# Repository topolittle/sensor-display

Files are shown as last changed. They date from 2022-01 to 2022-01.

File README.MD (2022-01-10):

# Sensor display monitor
This is a complete project to display temperature, fan speed and power consumption to a small 2x20 LCD display. The head unit fits a 5.25 standard PC drive bay.

## Features
Head unit:
- Arduino based
- 6 modes of operation
- Enclosure printable without supports

SystemD service (PC):
- Fully customizable using a configuration file
- Installation script included
- Written in Python
- Linux Support

## What's included
- Bill of material
- 3D Models (Step, Solidwork and STL)
- Electrical schematic
- Source code for the head unit (Arduino based)
- Source code for the service that monitor and send the data to the head unit
- VSCode devcontainer environment for the service and the head unit
- Some pictures of the final product

## Licenses
[Mechanical parts](MECHA/COPYING.TXT)  
[Head unit (Arduino)](SOFT/Arduino/COPYING.TXT)  
[SystemD Service (PC)](SOFT/PC/COPYING.TXT)  

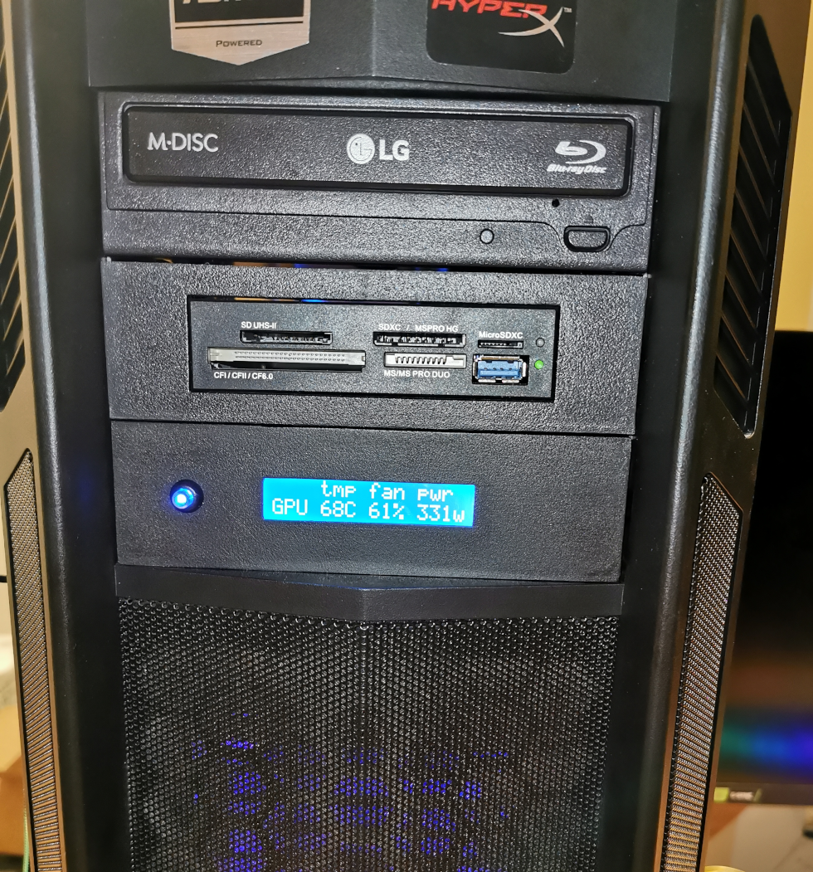
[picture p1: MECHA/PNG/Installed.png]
Picture of the head unit installed into a PC enclosure


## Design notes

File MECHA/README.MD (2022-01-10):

# Sensor display unit enclosure

This enclosure has been designed to fit into a 5.25" PC bay.

## Printer setting
Printed on a Flashforge Creator Pro FDM 3D printer.
- Material: ASA (Formfutura ApolloX)
- Position: Front panel face down on the bed
- Supports: No
- Finish: Some Acetone smooting for the front panel

## Credits
The assembly and the artwork uses some 3rd parties parts. Here is the list:  
**Pro micro Arduino PCB**  
Author: Andrew_Whitham  
URL: https://grabcad.com/library/arduino-pro-micro-1

**LCD Display**  
Author: Vin.X.Mod  
URL: https://grabcad.com/library/1602-lcd-display-1  

**M2 Screws**  
Author: Ioan Skurka  
URL: https://grabcad.com/library/all-m2-sh-standard-screws-m2-hex-nut-and-flat-washer-for-m2-screw-1

**5.25" drive bay**  
Author: Shashank Chintalagiri  
URL: https://grabcad.com/library/generic-5-25-bay-devices-1  
Note: This modes was used only for reference mesurements.

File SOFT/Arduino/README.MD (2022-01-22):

# SENSOR DISPLAY UNIT - EMBEDDED CODE
This is the code for the sensor display unit.
It target the Keystudio Ks0503 Pro Micro board but any Atmel ATMEGA 32U4 Arduino
board with an Leonardo bootloader should do the job. It's designed to fit in
a standard 5.25" PC drive bay.  
The device is powered by a single Molex 4 pin PC power connecter and it gets its data from a service running on the PC through an RS232 serial connection.

Please refers to the schematic diagram for the wiring of the board.
For the complete part list, refers to the bill of material document (BOM).

## Features
The unit has two modes of operation:
- Sensor display
- Configuration
In the sensor display mode, the display will display the current stored sensors values.
In the configuration mode, the display will cycle through all the available settings. Refers to the 'settings' section for more information.

## Settings
When pushing the button, the unit enters the configuration mode. Each subsequent button push will cycle to the next setting. Here is the list of all available configuration:
- SYSTEM: Display the system temperature and fan RPM
- CPU: Display the CPU temperature and fan RPM
- GPU: Display the GPU temperature, fan percentage and power consumption
- ALL (TEMP): Display the system, CPU and GPU temperature
- ALL (FAN): Display the system, CPU and GPU fan RPM or percentage
- AUTO: Cycle through SYSTEM, CPU and GPU every 3 seconds
- BUTTON LED OFF: Turn off the button blue LEDssss
- BUTTON LED HIGH: Turn on the button blue LED at high intensity
- BUTTON LED LOW: Turn on the button blue LED at low intensity

After 3 seconds of inactivity, the unit will revert to sensor display mode, the new configuration is saved to the persistent memory (EEProm) and it take effect immediately.

## Dependencies
The code requires the following libraries to be installed:  
**LiquidCrystal I2C**  
Version: 1.1.2  
Author: Frank de Brabander  
URL: https://github.com/marcoschwartz/LiquidCrystal_I2C

**Wire (Build-in library)**  
Version: 1.0.0  
Author: Nicholas Zambetti  
URL: https://www.arduino.cc/en/Reference/Wire

**EEPROM (Build-in library)**  
Version: 2.0.0  
Authors: David A. Mellis. and Christopher Andrews  
URL: https://www.arduino.cc/en/Reference/EEPROM

Note: If your are using the included VSCode devcontainer, libraries are already included and installed.

# Serial commands
Each serial command has the forms of `CCV..V;` where:
- 'CC' is a two chars command code
- 'V' is one or more numeric char that form the value associated with the command
- ';' is a marker char and signals the end of a command  
 Multiple command can be received on the same line, for example the
 command `ST34;CT55;GT67;CF1152;` will sets the system temperature
 to 34 celcius, the CPU temperature to 55 celcius and the CPU fan speed to 1152 RPM.  
 Refer to the source code to the complete list of accepted commands.
 
# Using with Visual Studio Code
## Using the devcontainer
The devcontainer is a self-contained environment that allows to compiles and upload
Arduino source code without having to install anything on your computer. You just need Docker.
[More Information about VSCode devcontainer here.](https://code.visualstudio.com/docs/remote/containers)
1. Open this folder (where this README.MD is located)
2. Hit Shift-CTRL-P  to open the command palette
3. Type and select: Remote-Containers: Reopen in Container

## Inside the devcontainer
You will have access to intellisense, syntax highlighting, build, upload and many more.
Take a look [here](https://marketplace.visualstudio.com/items?itemName=vsciot-vscode.vscode-arduino) for the available features.

### Commands in a nutshell
**Build / Verify:** ALT+CTRL+R  
**Upload:** ALT+CTRL+U

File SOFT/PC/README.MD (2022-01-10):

# SENSOR MONITOR SERVICE
This is the source code for the service that sends the sensor information
of the CPU, GPU and System to the head unit over a serial port.

## Features
- Linux support
- SystemD unit configuration included
- Install/Uninstall script included
- Fully customizable using a configuration file
- Verbose option for debugging

## Depencies
The code was tested using Python 3.9. However, it may works with an earlier version.
The following Python libraries are required to be installed in the system prior the service installation:
- pyserial
- nvidia-ml-py

## Installation
Simply run the install script as root.  
The script will deploy the following:
- The main sensor_monitor program and its compagnon files to /opt/sensor-monitor
- The configuration file in /etc/sensor-monitor
- The SystemD service unit in /etc/systemd/system  

The script will start and enable the service to start when the system boot.

Note: The install script didn't install the required Python dependencies by itself. You have to install it manually with the `pip3` command.  

Once the installation is completed, you may want to review the configuration file and adjust it to match your system configuration.

## Development
This project includes a VScode devcontainer based on Alpine. Currently the serial port is working from inside the container, but access to the GPU API is not yes supported.

## Future work
- Can be adapted to behave as a daemon using the python-daemon library which implement PEP 3143. This would allows sensor_monitor to work with SysV init.
- Add support for AMD GPUs
- Add a python setup to deploy the compagnon modules in the site-packages folder
- Add support for the GPU API in the devcontainer

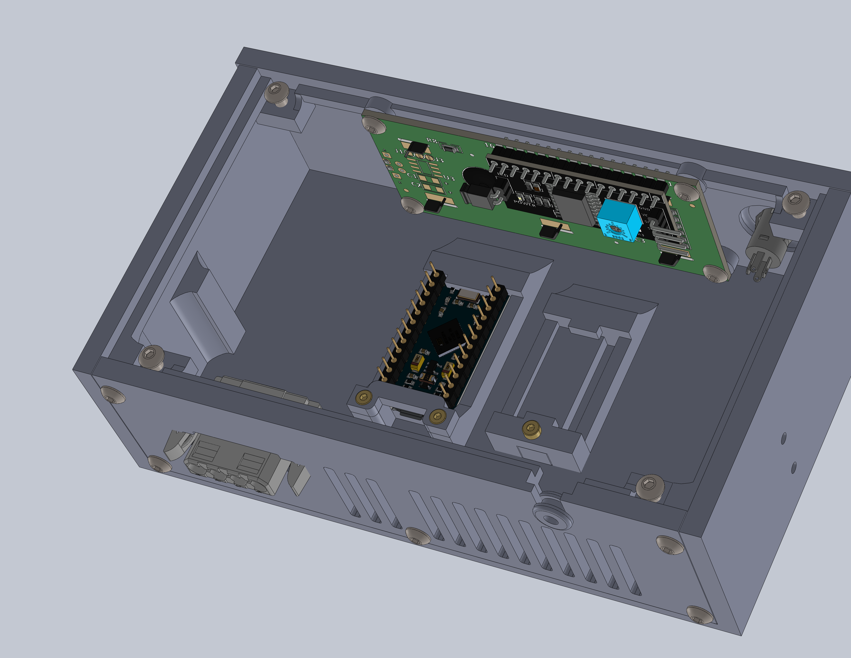
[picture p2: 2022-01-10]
MECHA/PNG/Complete_Unit_open_top.PNG

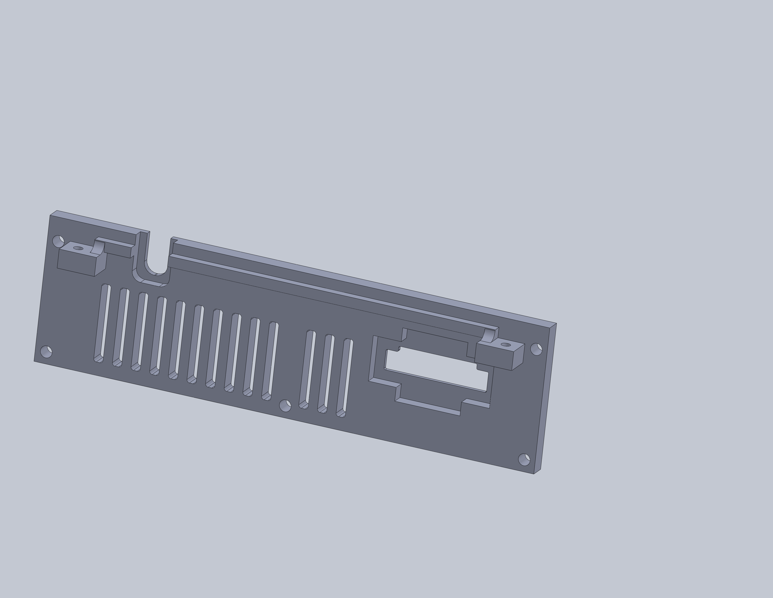
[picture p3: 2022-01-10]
MECHA/PNG/Back_plate.PNG

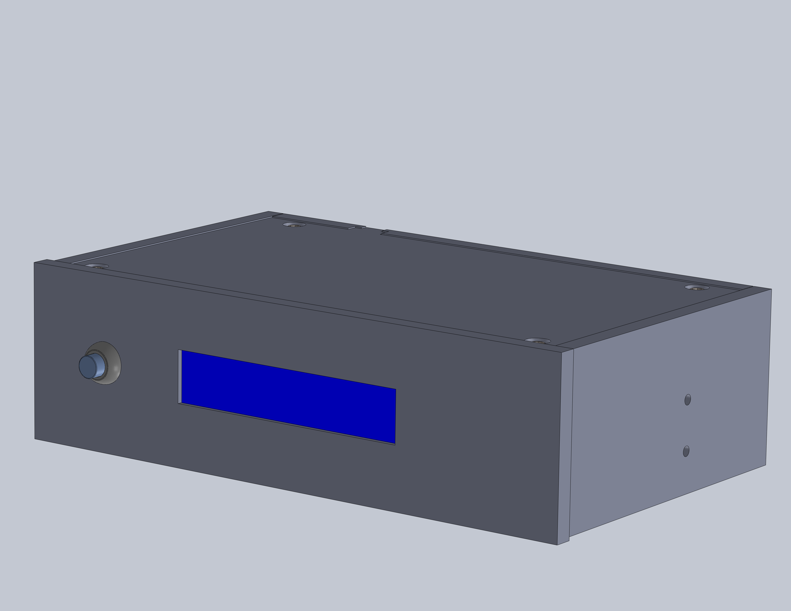
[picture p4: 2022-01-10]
MECHA/PNG/Complete_Unit_closed.PNG

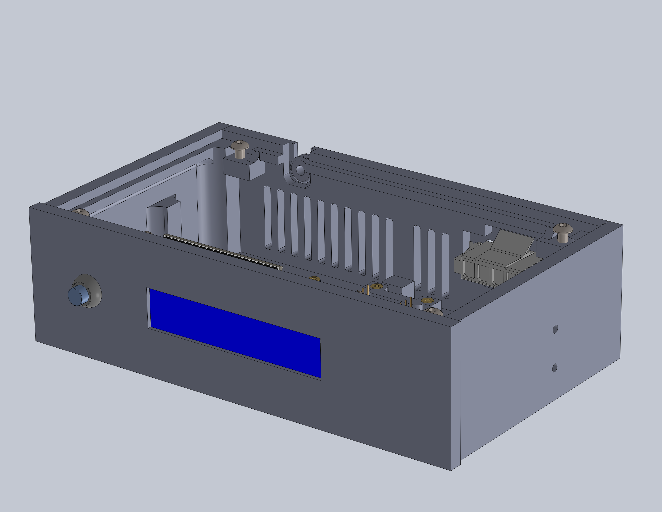
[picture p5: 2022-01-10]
MECHA/PNG/Complete_Unit_open.PNG

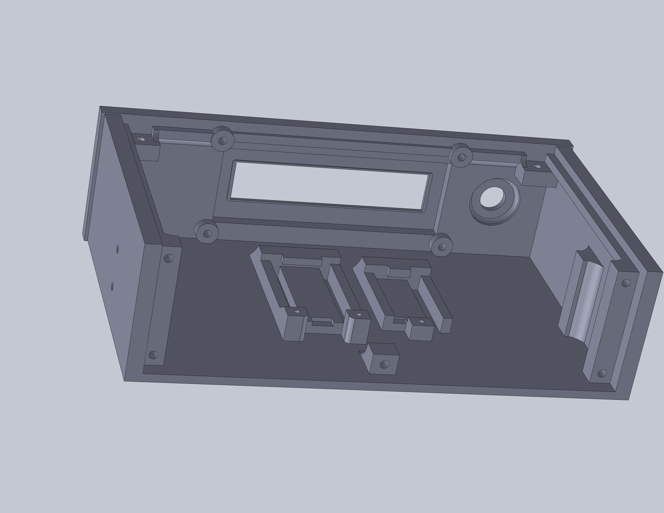
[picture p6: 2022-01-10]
MECHA/PNG/Enclosure_main.PNG

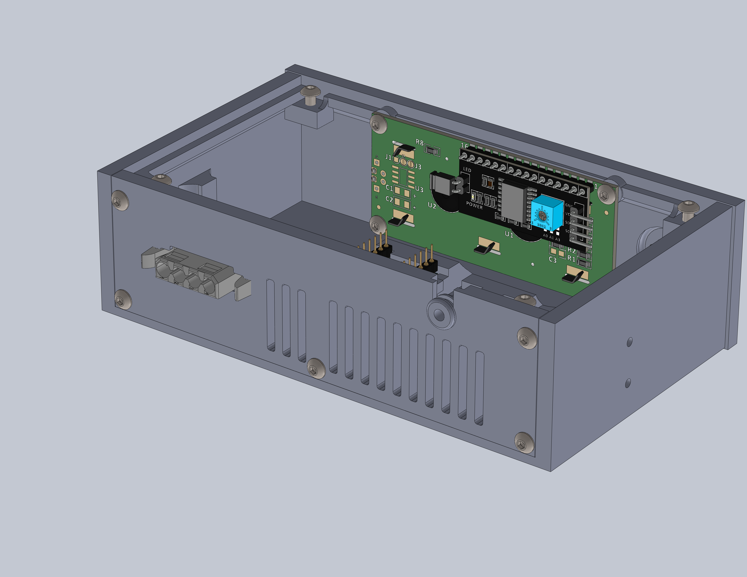
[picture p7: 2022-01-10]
MECHA/PNG/Complete_Unit_open_back.PNG

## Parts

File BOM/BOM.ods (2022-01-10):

Qty | Part No. | Manufacturer | Description
1 | KS0061 | Keyestudio | 1602a 2x16 LCD Module I2C
1 | KS0503 | Keyestudio | Pro Micro 5V ATmega32u4 (Leonardo)
1 | LP10A1AB | E-Switch | Pushbutton Switch SPST-NO w/blue LED
4 | M3 0.5 x 6mm | Generic | Round head machine screw (for LCD)
5 | M3 0.5 x 10mm | Generic | Round head machine screw (for back panel)
4 | M3 0.5 x 8mm | Generic | Round head machine screw (for top cover)
3 | M2 0.4 x 6mm | Generic | Round head machine screw (for Arduino and MAX3232)
1 | 11189 | Sparkfun | MAX3232 transceiver
1 | FH-A-A01B | Adam Tech | Fuse holder 5x20mm
1 | 1-480425-0 | AMP | Panel mount power connector
4 | 60617-1 | AMP | Mate N Lock connector pins
1 | 30-01410 | Tensility Int. Co. | Cable 26AWG 2 Cond. Shielded 1 Meter (For internal serial)
1 |  | Generic | 3/8" Grummet ID=0.244" OD=3/8" T=0.76"
1 |  | Generic | 1A / 250V Fuse 5x20mm
1 | PC0085 | DTECH | PCIe dual ports RS232 extension card
1 | 3-640442-9 | AMP | MTA-100 9 pos 26AWG (Blue)
1 | 4-640442-10 | AMP | MTA-100 10 pos 26AWG (Blue)
1 | 4-640442-4 | AMP | MTA-100 4 pos 26 AWG (Blue)
1 | 3-640442-2 | AMP | MTA-100 2 pos 24 AWG (White)
0.5 | 3811/10 300 | 3M | Ribbon cable 26AWG multicolor (0.5 Meter)

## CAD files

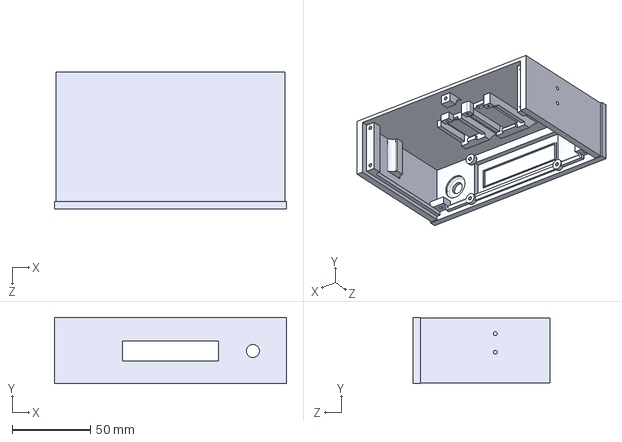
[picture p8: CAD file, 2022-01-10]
MECHA/STEP/Enclosure_main.STEP
148.0 x 42.3 x 87.1 mm

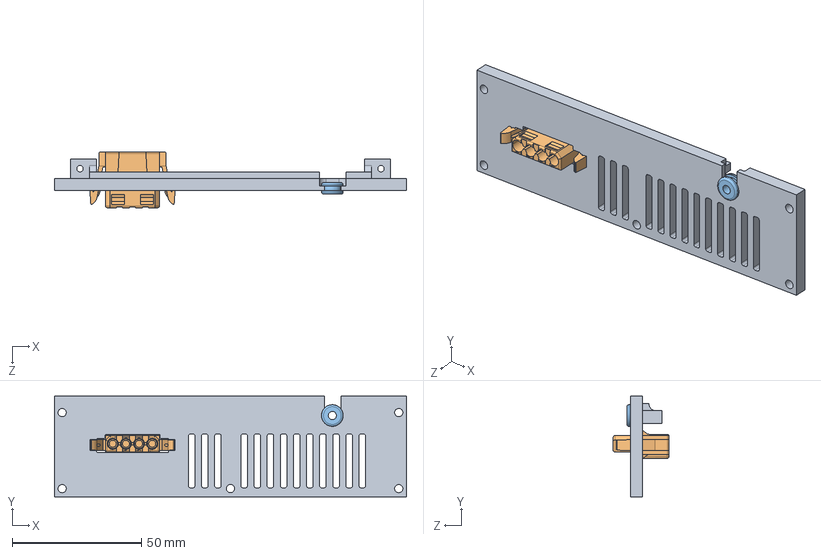
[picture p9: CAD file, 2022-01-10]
MECHA/SOLIDWORKS/Complete_Back_panel.SLDASM
136.2 x 39.0 x 21.7 mm
Back_plate
AMP-1-480425-0
Grommet_330

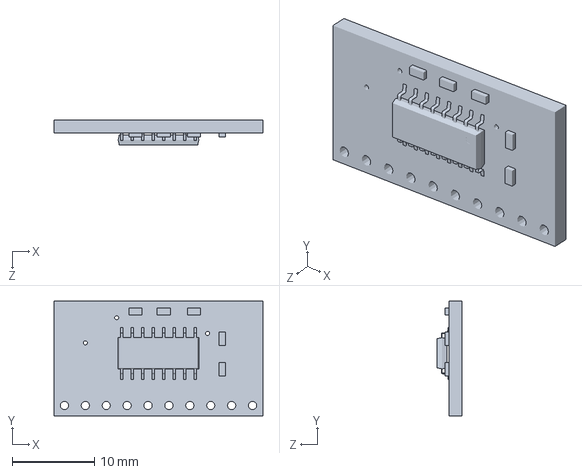
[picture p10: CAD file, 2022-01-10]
MECHA/SOLIDWORKS/SparkFun_MAX3232_Breakout.SLDPRT
25.4 x 14.0 x 3.06 mm

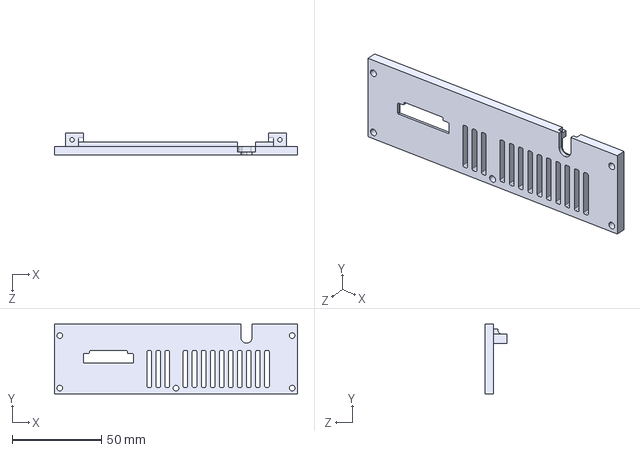
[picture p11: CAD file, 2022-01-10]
MECHA/STEP/Back_plate.STEP
136.2 x 39.0 x 12.3 mm

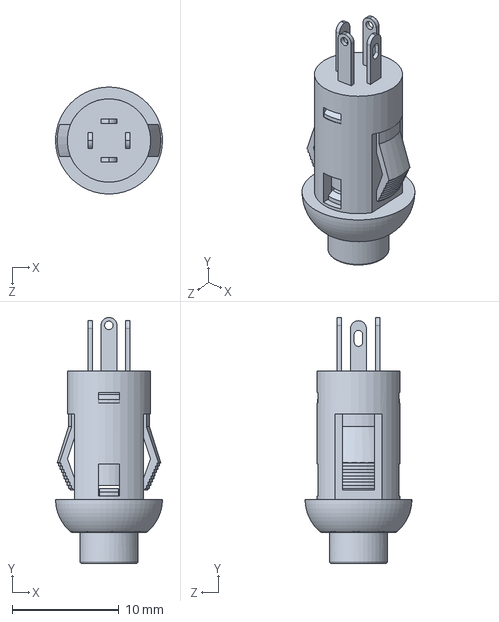
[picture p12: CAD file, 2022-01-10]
MECHA/SOLIDWORKS/LP1OA1Ax.SLDPRT
10.00 x 23.0 x 9.99 mm

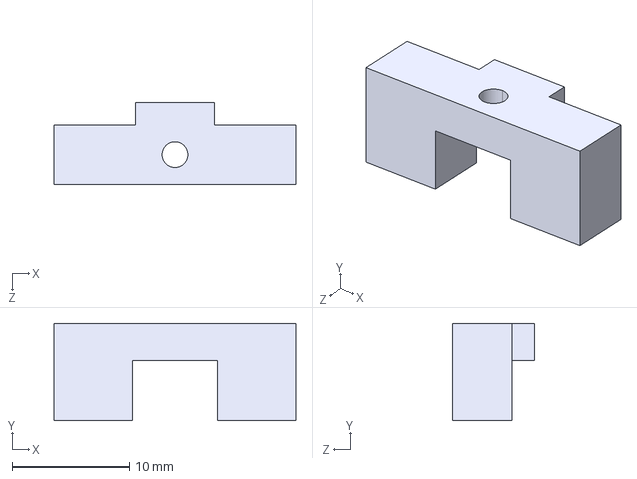
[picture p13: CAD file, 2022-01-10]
MECHA/STEP/max3232_holder.STEP
20.7 x 8.31 x 6.99 mm

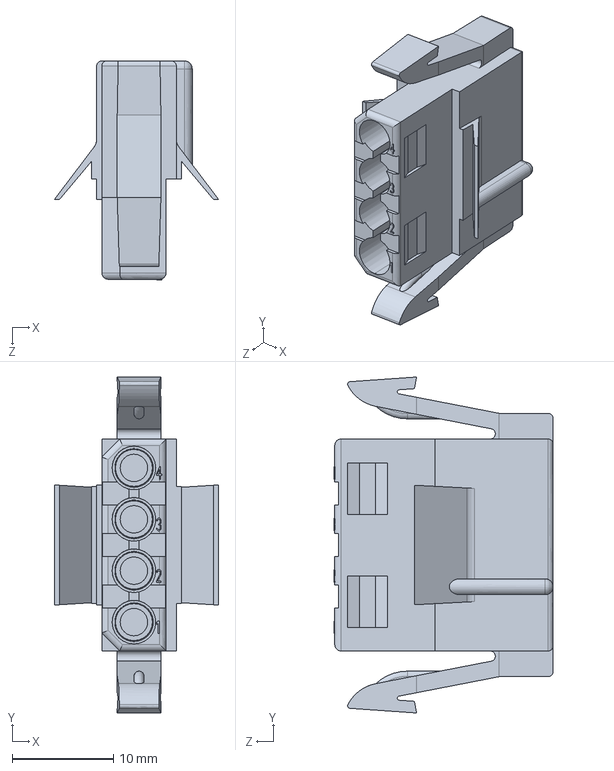
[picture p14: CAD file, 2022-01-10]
MECHA/SOLIDWORKS/AMP-1-480425-0.SLDPRT
16.3 x 33.2 x 21.7 mm

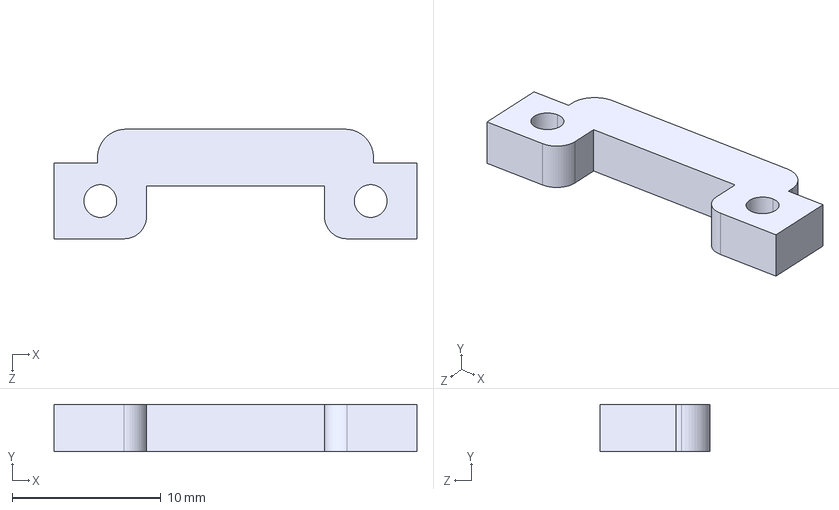
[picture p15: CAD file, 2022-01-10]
MECHA/STEP/Pro_midro_holder.STEP
24.4 x 3.17 x 7.37 mm

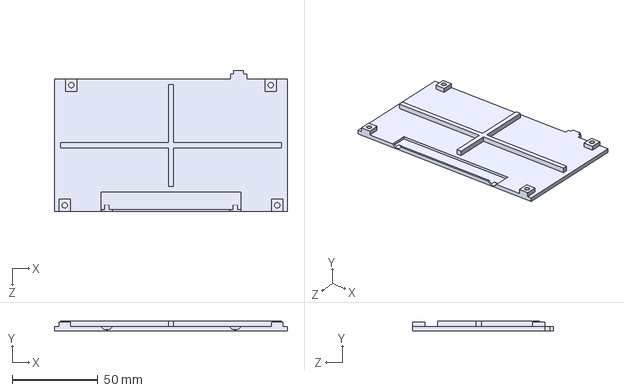
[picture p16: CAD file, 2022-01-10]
MECHA/STEP/Top_panel.STEP
136.1 x 5.72 x 82.3 mm

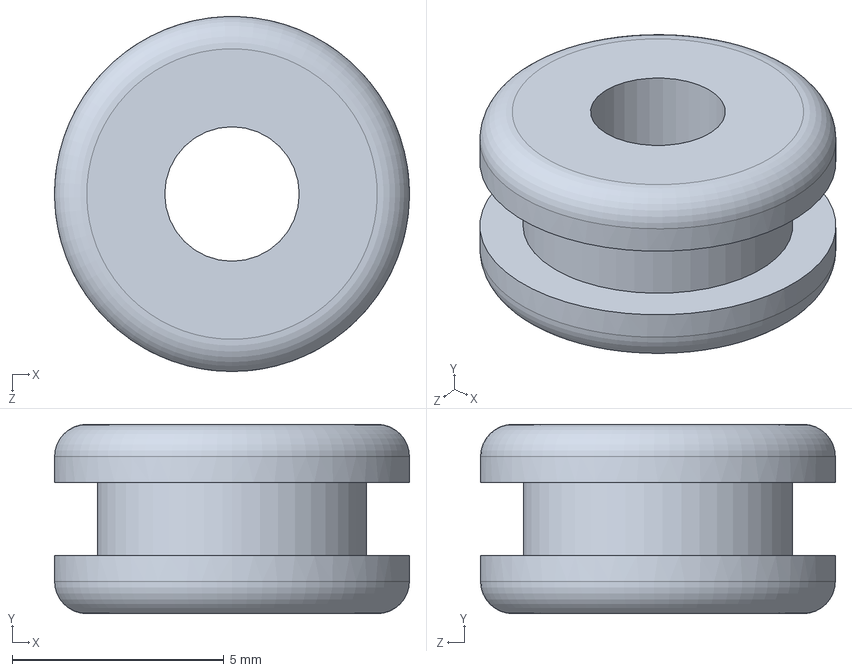
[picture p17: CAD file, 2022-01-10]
MECHA/SOLIDWORKS/Grommet_330.SLDPRT
8.38 x 4.47 x 8.38 mm

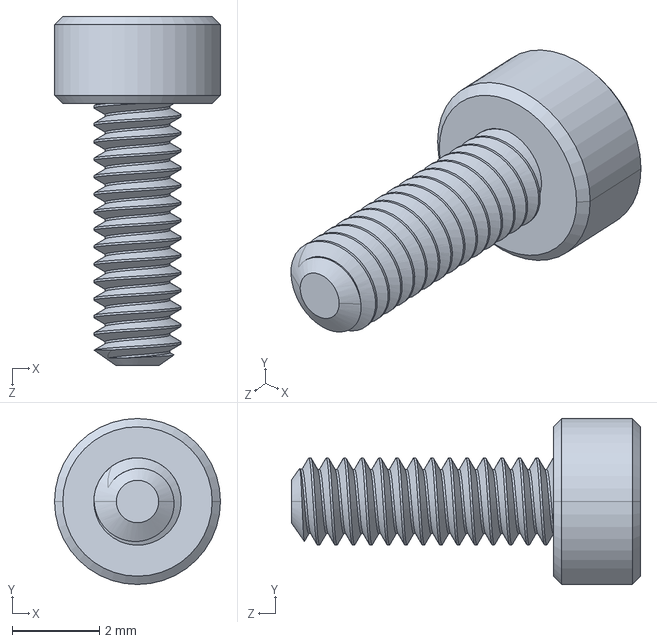
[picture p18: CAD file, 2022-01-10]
MECHA/SOLIDWORKS/M2-0.4x6mm_hex_screw.SLDPRT
3.80 x 3.80 x 8.00 mm

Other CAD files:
MECHA/SOLIDWORKS/Back_plate.SLDPRT
MECHA/SOLIDWORKS/Enclosure_main.SLDPRT
MECHA/SOLIDWORKS/Pro_midro_holder.SLDPRT
MECHA/SOLIDWORKS/Top_panel.SLDPRT
MECHA/SOLIDWORKS/max3232_holder.SLDPRT
MECHA/STL/Back_plate.STL
MECHA/STL/Enclosure_main.STL
MECHA/STL/Pro_midro_holder.STL
MECHA/STL/Top_panel.STL
MECHA/STL/max3232_holder.STL

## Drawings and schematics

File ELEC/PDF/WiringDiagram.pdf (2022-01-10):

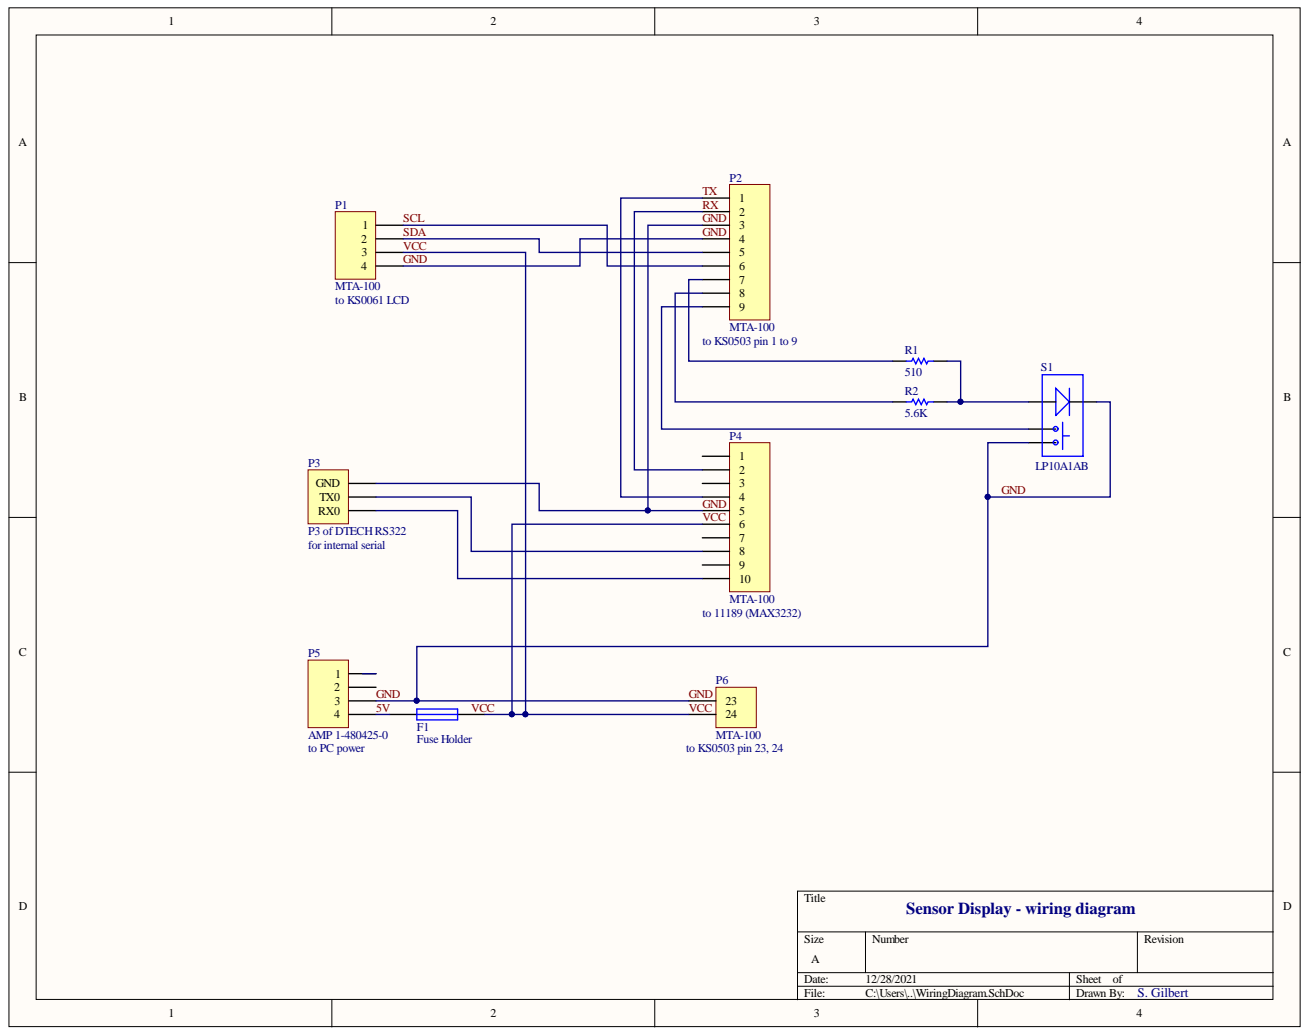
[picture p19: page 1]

S D A
V C C
GND

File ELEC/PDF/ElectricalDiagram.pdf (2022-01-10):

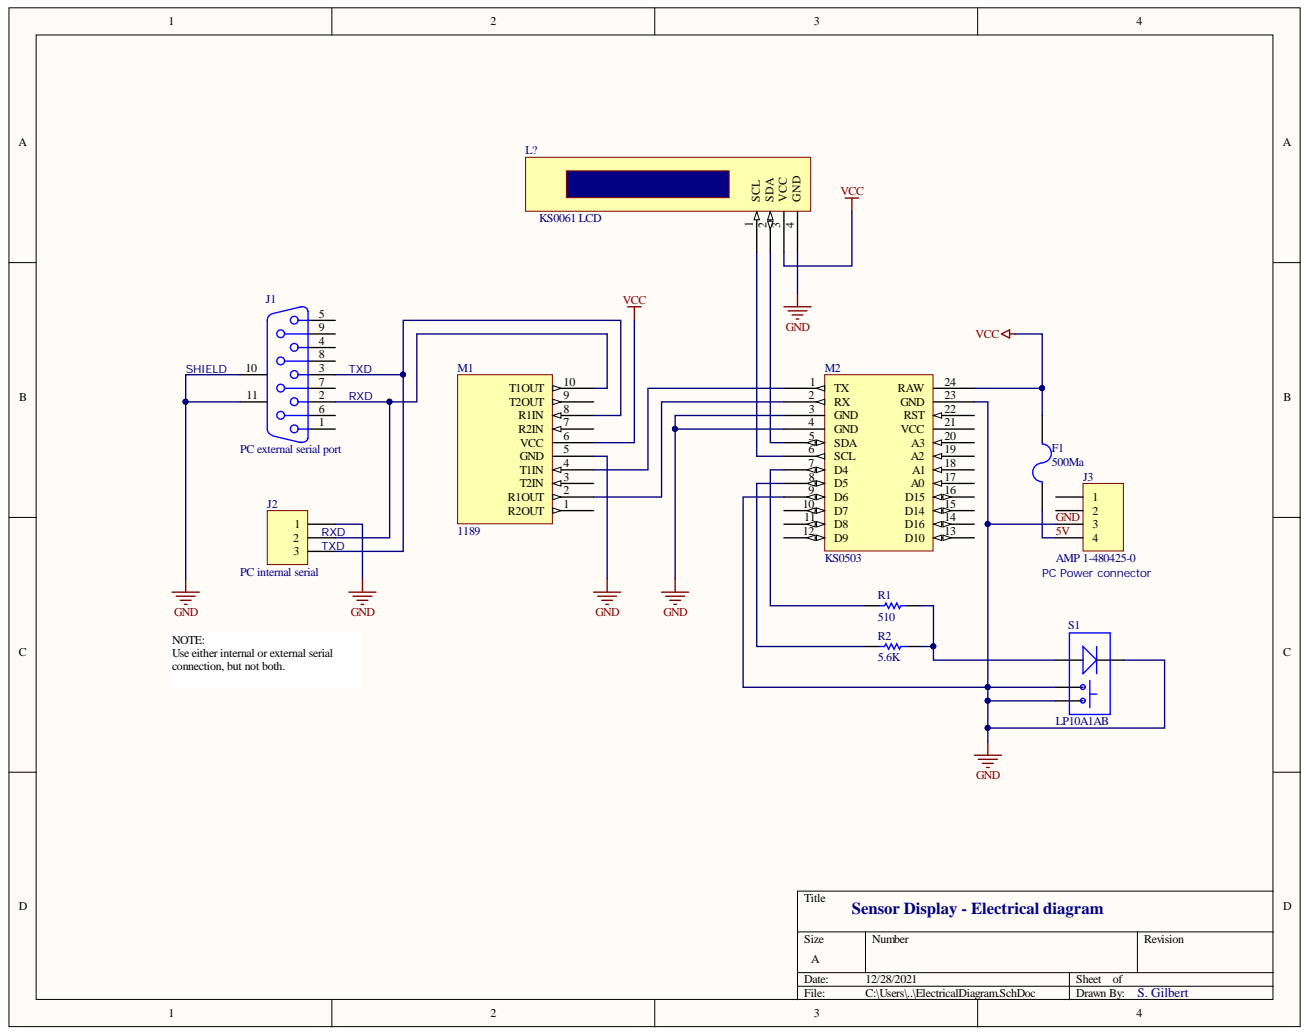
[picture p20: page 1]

9 | 2 | 2 3
8 | 3 | 2 2

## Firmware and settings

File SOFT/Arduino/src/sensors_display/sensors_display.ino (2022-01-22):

/* Source code for the sensor display head unit
 * Distributed under the GPLv2 License
 * Author: S. Gilbert
 */

#include <Wire.h>
#include <LiquidCrystal_I2C.h>
#include <EEPROM.h>
#include "sensors_display.h"

#pragma region global

LiquidCrystal_I2C lcd(LCD_I2C_ADDR, LCD_WIDTH, LCD_HEIGHT);
SensorItem CurrentSensorItem = (SensorItem)0;
ConfigItem CurrentConfigItem = (ConfigItem)0;
DisplayMode CurrentDisplayMode = DisplayMode::sensorCycle;
LedState CurrentLedState = LedState::High;
DisplayMode OldDisplayMode = CurrentDisplayMode;

/* Indicate wathever we need to update the display or not.
 * Should be set to true each time the display should be updated */
bool UpdateDisplay = true;

/* This indicate if we have received our first set of data
 * one it's set to true, it remains true */
bool DataAvailable = false;

/* The periode at which the CPU, GPU and system stats will cycle on the display */
u16 StatsDisplayTimeMs = STATS_DISPLAY_DEFAULT_TIME_MS;

// Defint an init values
u8 CPUTemp = 0;
u16 CPUFan = 0;
u8 GPUTemp = 0;
u8 GPUFan = 0;
u16 GPUPower = 0;
u8 SystemTemp = 0;
u16 SystemFan = 0;

#pragma endregion

/* Sets the button led according to the CurrentLedState variable */
void SetLed()
{
    switch (CurrentLedState)
    {
    case LedState::Off:
        pinMode(INPUT_BUTTON_LED_HIGH, INPUT);
        pinMode(INPUT_BUTTON_LED_LOW, OUTPUT);
        digitalWrite(INPUT_BUTTON_LED_LOW, LOW);
        break;
    case LedState::Low:
        pinMode(INPUT_BUTTON_LED_HIGH, INPUT);
        pinMode(INPUT_BUTTON_LED_LOW, OUTPUT);
        digitalWrite(INPUT_BUTTON_LED_LOW, HIGH);
        break;
    case LedState::High:
        pinMode(INPUT_BUTTON_LED_LOW, INPUT);
        pinMode(INPUT_BUTTON_LED_HIGH, OUTPUT);
        digitalWrite(INPUT_BUTTON_LED_HIGH, HIGH);
        break;
    }
}

/* Compute a parity on the EEProm data.
 * This is a very simple way to asses the integrity
 * of the stored data
 * @param eeprom data to compute
 * @return the calculated parity on 'eeprom' up to but the last byte */
u8 ComputeEepromParity(EepromData eeprom)
{
    u8 par = 0xff;
    u8 *eeprom_p = (u8 *)&eeprom;
    for (u16 i = 0; i < eeprom.Size - sizeof(eeprom.Pariry); i++)
    {
        par ^= eeprom_p[i];
    }

    return par;
}

/* Save the current config state to the EEPRom
 * @return a EepromData struct representing the saved data */
EepromData StoreDataToEeprom()
{
    EepromData eeprom;
    eeprom.Version = CURRENT_EEPROM_DATA_VERSION;
    eeprom.Size = sizeof(EepromData);
    eeprom.SelectedDisplayMode = (u8)CurrentDisplayMode;
    eeprom.SelectedSensorItem = (u8)CurrentSensorItem;
    eeprom.LedState = (u8)CurrentLedState;
    eeprom.StatsDisplayTimeMs = StatsDisplayTimeMs;
    eeprom.Pariry = ComputeEepromParity(eeprom);
    EEPROM.put(0, eeprom);
    return eeprom;
}

/* Load the previously saved state from the EEProm
* Validate version and data integrity and reset the
* EEProm data to a know state if they are not valid. */
void PopulateDataFromEeprom()
{
    EepromData eeprom;
    EEPROM.get(0, eeprom);

    if (eeprom.Version != CURRENT_EEPROM_DATA_VERSION || ComputeEepromParity(eeprom) != eeprom.Pariry)
    {
        // Reset the eeprom to a know state
        eeprom = StoreDataToEeprom();
    }

    CurrentDisplayMode = (DisplayMode)eeprom.SelectedDisplayMode;
    CurrentSensorItem = (SensorItem)eeprom.SelectedSensorItem;
    CurrentLedState = (LedState)eeprom.LedState;
    StatsDisplayTimeMs = eeprom.StatsDisplayTimeMs;
}

/* Read the push button and debounce its state
 * @return true if the button was activated and it's
 * fully debounced. Otherwise false. */
bool isButtonDebounced()
{
    static unsigned long lastDebounceTime = 0;
    static int buttonState = HIGH;
    static int lastButtonState = buttonState;
    bool state = false;
    int buttonReading;

    // Read the input button and debounce it
    buttonReading = digitalRead(INPUT_BUTTON);
    if (buttonReading != lastButtonState)
    {
        lastDebounceTime = millis();
    }

    lastButtonState = buttonReading;
    if ((millis() - lastDebounceTime) > DEBOUNCE_TIME_MS && buttonReading != buttonState)
    {
        buttonState = buttonReading;
        if (buttonState == BUTTON_PUSHED)
        {
            state = true;
        }
    }

    return state;
}

/* Look for data on the serial port and process it if present.
 * The data has the forms of CCV..V; where:
 * - 'CC' is a two chars command code
 * - 'V' is one or more numeric char that form the value associated with the command
 * - ';' is a marker char that signal the end of a command.
 * Multiple command can be received on the same line, for example the
 * command 'ST34;CT55;GT67;CF1152;' without quote will set the system temperature
 * to 34 celcius, the CPU temperature to 55 celcius and the CPU fan speed to 1152 RPM.
 *
 *  Here is the supported serial commands.
 *
 *  Sets CPU temperature in Celcius
 *  CT<cpu_temp>;
 *
 *  Sets CPU fan in rotation per minutes
 *  CF<fan_rpm>;
 *
 *  Sets GPU temperature in Celcius
 *  GT<gpu_temp>;
 *
 *  Sets GPU fan percentage
 *  GF<fan_percent>;
 *
 *  Sets GPU power consumption
 *  GP<gpu_power>;
 *
 *  Sets the system temperature in Celcius
 *  ST<system_temp>;
 *
 *  Sets the system fan in rotation per minutes
 *  SF<system_fan>;
 * 
 * Sets the periode at which the CPU, GPU and system stats will cycle on the display, in milliseconds
 * DT<periode_ms>;
 * 
 * Sets the device in 'Awaiting Data' mode
 * AD;
 */
void processSerialData()
{
    if (Serial1.available() > 0)
    {
        String serData = Serial1.readStringUntil(';');
        String serCommand = serData.substring(0, 2);
        long serValue = serData.substring(2).toInt();
        DataAvailable = true;

        if (CurrentDisplayMode != DisplayMode::config)
        {
            UpdateDisplay = true;
        }

        if (serCommand == "CT")
        {
            CPUTemp = (u8)serValue;
        }
        else if (serCommand == "CF")
        {
            CPUFan = (u16)serValue;
        }
        else if (serCommand == "GT")
        {
            GPUTemp = (u8)serValue;
        }
        else if (serCommand == "GF")
        {
            GPUFan = (u8)serValue;
        }
        else if (serCommand == "GP")
        {
            GPUPower = (u16)serValue;
        }
        else if (serCommand == "ST")
        {
            SystemTemp = (u8)serValue;
        }
        else if (serCommand == "SF")
        {
            SystemFan = (u16)serValue;
        }
        else if (serCommand == "DT")
        {
            StatsDisplayTimeMs = (u16)serValue;
            StoreDataToEeprom();
        }
        else if (serCommand == "AD")
        {
            DataAvailable = false;
        }
    }
}

/* Display an amount of blank char to the LCD.
 * This can be useful to delete the remaining of the line
 * without using lcd.clear() beforehand
 * @param count the number of blank chars to display */
void DisplayBlankChar(u8 count)
{
    for (u8 i = 0; i < count; i++)
    {
        lcd.print(" ");
    }
}

/* Display the current configuration item.
 * Also, check whatever a timeout has occured and if so,
 * register the new configuration */
void ManageDisplayConfig()
{
    static unsigned long lastConfigTime = 0;

    if (UpdateDisplay)
    {
        lcd.clear();
        if ((u8)CurrentConfigItem <= (u8)ConfigItem::cycle)
        {
            lcd.setCursor(4, 0);
            lcd.print("DISPLAY");
        }
        else
        {
            lcd.setCursor(3, 0);
            lcd.print("BUTTON LED");
        }

        switch (CurrentConfigItem)
        {
        case ConfigItem::cpu:
            lcd.setCursor(6, 1);
            lcd.print("CPU");
            break;
        case ConfigItem::gpu:
            lcd.setCursor(6, 1);
            lcd.print("GPU");
            break;
        case ConfigItem::system:
            lcd.setCursor(5, 1);
            lcd.print("SYSTEM");
            break;
        case ConfigItem::allTemp:
            lcd.setCursor(3, 1);
            lcd.print("ALL (TEMP)");
            break;
        case ConfigItem::allFan:
            lcd.setCursor(3, 1);
            lcd.print("ALL (FAN)");
            break;
        case ConfigItem::cycle:
            lcd.setCursor(5, 1);
            lcd.print("AUTO");
            break;
        case ConfigItem::buttonLedOff:
            lcd.setCursor(6, 1);
            lcd.print("OFF");
            break;
        case ConfigItem::buttonLedLow:
            lcd.setCursor(6, 1);
            lcd.print("LOW");
            break;
        case ConfigItem::buttonLedHigh:
            lcd.setCursor(5, 1);
            lcd.print("HIGH");
            break;
        }

        UpdateDisplay = false;
        lastConfigTime = millis();
    }
    else if ((millis() - lastConfigTime) > CONFIG_DISPLAY_TIME_MS)
    {
        // Reset the display to sensors and set the new config
        switch (CurrentConfigItem)
        {
        case ConfigItem::cpu:
            CurrentDisplayMode = DisplayMode::sensor;
            CurrentSensorItem = SensorItem::cpu;
            break;
        case ConfigItem::gpu:
            CurrentDisplayMode = DisplayMode::sensor;
            CurrentSensorItem = SensorItem::gpu;
            break;
        case ConfigItem::system:
            CurrentDisplayMode = DisplayMode::sensor;
            CurrentSensorItem = SensorItem::system;
            break;
        case ConfigItem::allTemp:
            CurrentDisplayMode = DisplayMode::sensor;
            CurrentSensorItem = SensorItem::allTemp;
            break;
        case ConfigItem::allFan:
            CurrentDisplayMode = DisplayMode::sensor;
            CurrentSensorItem = SensorItem::allFan;
            break;
        case ConfigItem::cycle:
            CurrentDisplayMode = DisplayMode::sensorCycle;
            CurrentSensorItem = (SensorItem)0;
            break;
        case ConfigItem::buttonLedOff:
            CurrentDisplayMode = OldDisplayMode;
            CurrentLedState = LedState::Off;
            SetLed();
            break;
        case ConfigItem::buttonLedLow:
            CurrentDisplayMode = OldDisplayMode;
            CurrentLedState = LedState::Low;
            SetLed();
            break;
        case ConfigItem::buttonLedHigh:
            CurrentDisplayMode = OldDisplayMode;
            CurrentLedState = LedState::High;
            SetLed();
            break;
        }

        UpdateDisplay = true;
        StoreDataToEeprom();
    }
}

/* Display the sensor value according to the current configuration.
 * When the configuration is set to 'sensorCycle', it also cycle to
 * every sensors */
void ManageDisplaySensor()
{
    static unsigned long lastChangeTime = 0;
    char line1[(LCD_WIDTH + 1) * sizeof(char)];
    char line2[(LCD_WIDTH + 1) * sizeof(char)];
    char gpuChar[4];

    if (CurrentDisplayMode == DisplayMode::sensorCycle && ((millis() - lastChangeTime) > ((unsigned long)StatsDisplayTimeMs)))
    {
        // Here we have to move to another sensor
        lastChangeTime = millis();
        CurrentSensorItem = (SensorItem)((u8)(CurrentSensorItem) + 1);
        if (CurrentSensorItem == SensorItem::allTemp)
            CurrentSensorItem = (SensorItem)0;
        UpdateDisplay = true;
    }

    if (UpdateDisplay)
    {
        memset(line1, '\0', sizeof(char));
        memset(line2, '\0', sizeof(char));
        if (DataAvailable)
        {
            // Prepare the message to be displayed
            sprintf(line1, "    tmp fan");
            if (GPUFan >= 100)
            {
                sprintf(gpuChar, "MAX");
            }
            else
            {
                sprintf(gpuChar, "%2d%%", GPUFan % 100);
            }

            switch (CurrentSensorItem)
            {
            case SensorItem::cpu:
                sprintf(line2, "CPU %2dC %d rpm", CPUTemp % 100, CPUFan % 10000);
                break;
            case SensorItem::gpu:
                sprintf(line1, "    tmp fan pwr");
                sprintf(line2, "GPU %2dC %s %dw", GPUTemp % 100, gpuChar, GPUPower % 1000);
                break;
            case SensorItem::system:
                sprintf(line2, "SYS %2dC %d rpm", SystemTemp % 100, SystemFan % 10000);
                break;
            case SensorItem::allTemp:
                sprintf(line1, " SYS  CPU  GPU");
                sprintf(line2, " %2dC  %2dC  %2dC", SystemTemp % 100, CPUTemp % 100, GPUTemp % 100);
                break;
            case SensorItem::allFan:
                sprintf(line1, " SYS   CPU   GPU");
                sprintf(line2, "%4d  %4d   %s", SystemFan % 10000, CPUFan % 10000, gpuChar);
                break;
            }
        }
        else
        {
            sprintf(line1, " AWAITING DATA");
        }

        lcd.setCursor(0, 0);
        lcd.print(line1);
        DisplayBlankChar(LCD_WIDTH - strlen(line1));
        lcd.setCursor(0, 1);
        lcd.print(line2);
        DisplayBlankChar(LCD_WIDTH - strlen(line2));
        UpdateDisplay = false;
    }
}

/* Display either the configuration or the sensors
 * according to the current display mode */
void ManageDisplay()
{
    if (CurrentDisplayMode == DisplayMode::config)
    {
        ManageDisplayConfig();
    }

    ManageDisplaySensor();
}

void setup()
{
    lcd.init();
    lcd.clear();
    lcd.backlight();

    pinMode(INPUT_BUTTON, INPUT_PULLUP);
    Serial1.begin(115200);
    PopulateDataFromEeprom();
    SetLed();
}

void loop()
{
    while (true)
    {
        if (isButtonDebounced())
        {
            if (CurrentDisplayMode != DisplayMode::config)
            {
                OldDisplayMode = CurrentDisplayMode;
                CurrentDisplayMode = DisplayMode::config;
                CurrentConfigItem = (ConfigItem)0;
            }
            else
            {
                CurrentConfigItem = (ConfigItem)((u8)CurrentConfigItem + 1);
                if (CurrentConfigItem == ConfigItem::endEnum)
                {
                    CurrentConfigItem = (ConfigItem)0;
                }
            }

            UpdateDisplay = true;
        }

        ManageDisplay();
        processSerialData();
    }
}

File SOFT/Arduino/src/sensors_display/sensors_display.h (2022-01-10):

#ifndef SENSOR_DISPLAY_H_
#define SENSOR_DISPLAY_H_

#define LCD_I2C_ADDR 0x27
#define LCD_WIDTH 16 // The number of char per line the lcd has
#define LCD_HEIGHT 2 // The number of lines the lcd has

#define INPUT_BUTTON_LED_HIGH 5
#define INPUT_BUTTON_LED_LOW 4
#define INPUT_BUTTON 6
#define DEBOUNCE_TIME_MS 30L
#define BUTTON_PUSHED LOW
#define BUTTON_RELEASED HIGH

#define STATS_DISPLAY_DEFAULT_TIME_MS 3000
#define CONFIG_DISPLAY_TIME_MS 3000

#define CURRENT_EEPROM_DATA_VERSION 1

/* Enum that define what sensor reading to display */
enum class SensorItem : u8 {
    system = 0,
    cpu,
    gpu,
    allTemp,
    allFan,
    endEnum
};

/* Enum that define the configuration selection */
enum class ConfigItem : u8 {
    system = 0,
    cpu,
    gpu,
    allTemp,
    allFan,
    cycle,
    buttonLedOff,
    buttonLedHigh,
    buttonLedLow,
    endEnum
};

/* Enum that define the display modes */
enum class DisplayMode : u8 {
    sensor = 0,
    sensorCycle,
    config
};

/* Enum that define the various led states */
enum class LedState : u8 {
    Off = 0,
    Low ,
    High
};

/* Represent the eeprom data structure
 * Add any new item before the parity field. */
struct EepromData
{
    u8 Version;
    u8 Size;
    u8 SelectedDisplayMode;
    u8 SelectedSensorItem;
    u8 LedState;
    u16 StatsDisplayTimeMs;
    u8 Pariry;
};

#endif // SENSOR_DISPLAY_H_

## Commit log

2022-01-22 Arduino: Improved the README
2022-01-22 Arduino: Added support for the 'AD' serial command
